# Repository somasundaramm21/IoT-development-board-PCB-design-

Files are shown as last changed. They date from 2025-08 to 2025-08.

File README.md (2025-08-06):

# IoT-development-board-PCB-design-
PCB Design and Kicad files for IoT development board

# 🔧 ESP32-C3 IoT Development Board – Designed with KiCad 8

This repository showcases the complete design journey of a **medium-complexity, four-layer IoT development board**, created using **KiCad 8**. The board features the **ESP32-C3** microcontroller along with built-in **environmental sensors**, **flash memory**, **microSD card support**, and a robust **power management system**—making it a powerful and flexible platform for modern IoT applications.

Unlike previous KiCad projects where I only explored new features, this time I set out to **test KiCad 8 in a real-world design workflow**—from schematic to layout, all the way to manufacturing and hardware validation. The result is this versatile, fully functional development board, designed, tested, and optimized using KiCad 8's latest capabilities.

---

## ✨ Key Features

- ✅ Real-world hardware tested with iterative debugging
- 🛠️ Designed entirely in **KiCad 8**
- ⚡️ Powered by **ESP32-C3** (RISC-V + Wi-Fi + BLE)
- 🔋 Battery and USB-C powered with onboard charging circuit
- 📦 Includes **SPI flash** and **microSD card** for flexible data storage
- 🌡️ Built-in sensors for real-time environmental monitoring
- 🧠 Expandable with AI/LLM capabilities using OpenAI-ESP32

---

## 📐 Tech Specs

### 🧠 Core Components

- **Microcontroller**: ESP32-C3 (RISC-V, Wi-Fi 4, Bluetooth Low Energy)
- **Power Input**: USB-C (for power and data) or LiPo battery (via JST)
- **Power Management**:
  - Dedicated LiPo charging circuit
  - Onboard 3.3V and 5V voltage regulators
- **Storage**:
  - MicroSD card slot for local logging
  - External SPI Flash for config/firmware/data

### 🌡️ Sensors & Inputs

- **BME280**: Temperature, humidity, and pressure
- **Ambient Light Sensor**
- **Microphone with Pre-Amplifier**: Sound monitoring and audio input

### 🔌 Interfaces

- **Protocols**: I2C, SPI
- **USB-to-UART Bridge**: For easy programming and serial debugging
- **GPIO Header**: Expandable for external devices/sensors
- **Test Points**: Available for hardware probing and diagnostics

### 🎛️ User Interaction

- **Buttons**: Boot and Reset
- **Indicators**: Status LEDs for power, charge, and operation
- **Form Factor**:
  - 4-layer PCB (signal, power, and ground planes)
  - Compact and EMI-conscious layout
  - Designed for manufacturability and hand-assembly

---

## 🌍 Applications

This board is a multipurpose platform designed for both prototyping and deployment in:

### 📊 Environmental Monitoring
Use the BME280 and light sensor to build smart weather stations, monitor air quality, or automate greenhouse conditions.

### 🧪 Data Logging
With both SPI flash and SD card, this board is perfect for remote or mobile data logging applications like field research or industrial monitoring.

### 🔋 Battery-Powered IoT Devices
Efficient power management and LiPo support allow you to create portable IoT nodes, wearables, or smart agriculture tools.

### 🔊 Audio-Responsive Systems
Use the microphone + preamp setup for audio monitoring, voice triggers, or sound-based analytics.

---

## 🤖 AI Integration with OpenAI-ESP32

This board is not just for sensors and data—it's also designed for **edge AI experiments**.

With the **OpenAI-ESP32 Arduino library** provided by Espressif, your IoT board can now:

- 🔈 **Understand Voice Commands**  
  Use the onboard microphone to build a smart home assistant that reacts to your natural language.

- 📈 **Analyze Sensor Trends**  
  Combine sensor data with OpenAI’s LLMs to generate meaningful summaries, alerts, or insights.

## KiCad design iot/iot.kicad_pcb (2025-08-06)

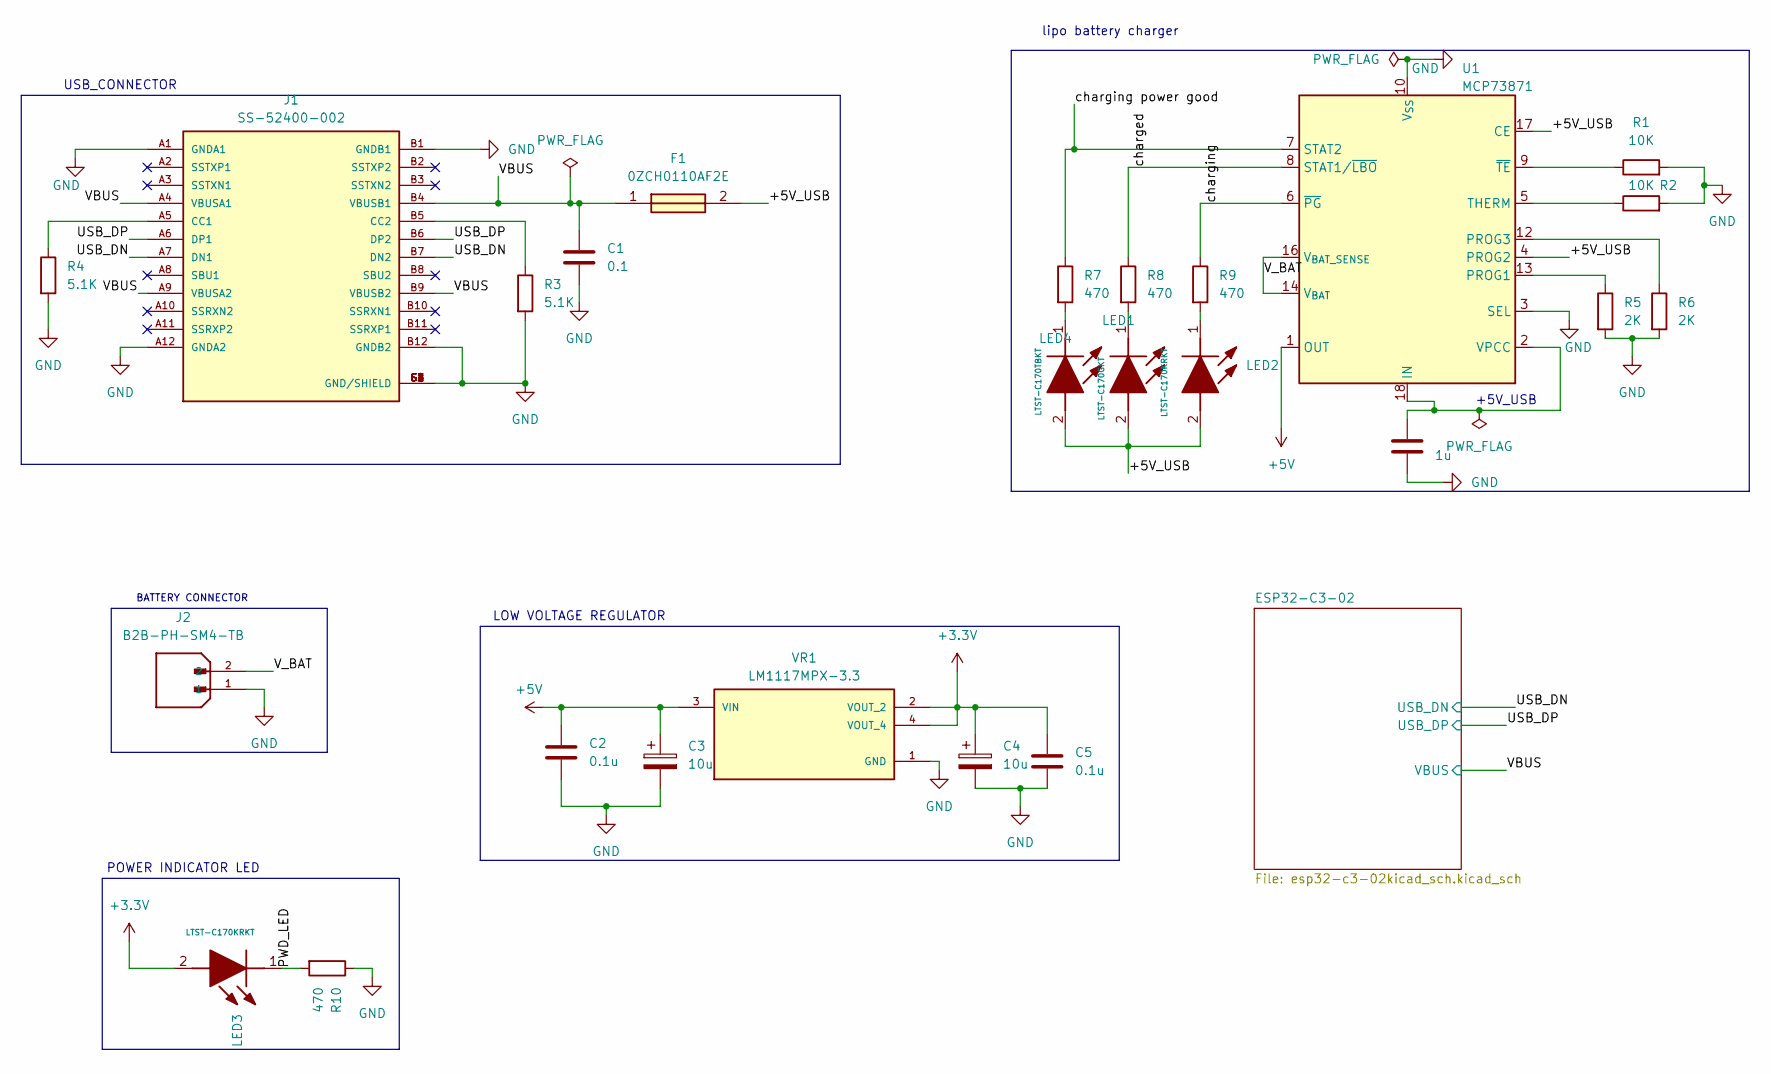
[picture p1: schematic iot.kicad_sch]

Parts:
C1: 0.1; C_0805_2012Metric
C2, C5: 0.1u; C_0805_2012Metric
C3, C4: 10u; RESC3216X125N
C6: 1u; C_0805_2012Metric
F1: 0ZCH0110AF2E; FUSC3226X100N; Manufacturer_Part_Number 0ZCH0110AF2E
J1: SS-52400-002; BELFUSE_SS-52400-002; PARTREV A0
J2: B2B-PH-SM4-TB; JST_B2B-PH-SM4-TB; PARTREV N/A
LED1: LTST-C170GKT; LEDC2012X120N; Manufacturer_Part_Number LTST-C170GKT; Mouser Part Number 859-LTST-C170GKT
LED2, LED3: LTST-C170KRKT; LEDC2012X120N; Manufacturer_Part_Number LTST-C170KRKT; Mouser Part Number 859-LTST-C170KRKT
LED4: LTST-C170TBKT; LEDC2012X120N; Manufacturer_Part_Number LTST-C170TBKT; Mouser Part Number 859-LTST-C170TBKT
R1, R2: 10K; R_0805_2012Metric
R3, R4: 5.1K; R_0805_2012Metric
R5, R6: 2K; R_0805_2012Metric
R7, R8, R9, R10: 470; R_0805_2012Metric
U1: MCP73871; QFN-20-1EP_4x4mm_P0.5mm_EP2.5x2.5mm
VR1: LM1117MPX-3.3; VREG_LM1117MPX-3.3; PARTREV O

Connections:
+3.3V: C4.1, C5.1, LED3.2 (A), VR1.2 (VOUT_2), VR1.4 (VOUT_4); also elsewhere on the board
+5V: C2.1, C3.1, U1.1 (OUT), U1.20 (OUT), VR1.3 (VIN)
/PWD_LED: LED3.1 (K), R10.2
/USB_DN: J1.A7 (DN1), J1.B7 (DN2); also elsewhere on the board
/USB_DP: J1.A6 (DP1), J1.B6 (DP2); also elsewhere on the board
/VBUS: C1.1, F1.1, J1.A4 (VBUSA1), J1.A9 (VBUSA2), J1.B4 (VBUSB1), J1.B9 (VBUSB2); also elsewhere on the board
/V_BAT: J2.2, U1.14 (V_{BAT}), U1.15 (V_{BAT}), U1.16 (V_{BAT_SENSE})
/charged: R8.1, U1.8 (STAT1/~LBO)
/charging: R9.1, U1.6 (~PG)
/charging power good: R7.1, U1.7 (STAT2)
GND: C1.2, C2.2, C3.2, C4.2, C5.2, C6.2, J1.A1 (GNDA1), J1.A12 (GNDA2), J1.B1 (GNDB1), J1.B12 (GNDB2), J1.G1 (GND/SHIELD), J1.G2 (GND/SHIELD), J1.G3 (GND/SHIELD), J1.G4 (GND/SHIELD), J1.S1 (GND/SHIELD), J1.S2 (GND/SHIELD), J1.S3 (GND/SHIELD), J1.S4 (GND/SHIELD), J2.1, R1.2, R2.2, R3.2, R4.2, R5.2, R6.2, R10.1, U1.3 (SEL), U1.10 (V_{SS}), U1.11 (V_{SS}), U1.21 (V_{SS}), VR1.1 (GND); also elsewhere on the board
unnamed: J1.A5 (CC1), R4.1
unnamed: J1.B5 (CC2), R3.1
unnamed: LED1.1 (K), R8.2
unnamed: LED2.1 (K), R9.2
unnamed: LED4.1 (K), R7.2
unnamed: R5.1, U1.13 (PROG1)
unnamed: R6.1, U1.12 (PROG3)
unnamed: R2.1, U1.5 (THERM)
unnamed: R1.1, U1.9 (~TE)

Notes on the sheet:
lipo battery charger
POWER INDICATOR LED
+5V_USB
USB_CONNECTOR
LOW VOLTAGE REGULATOR
BATTERY CONNECTOR

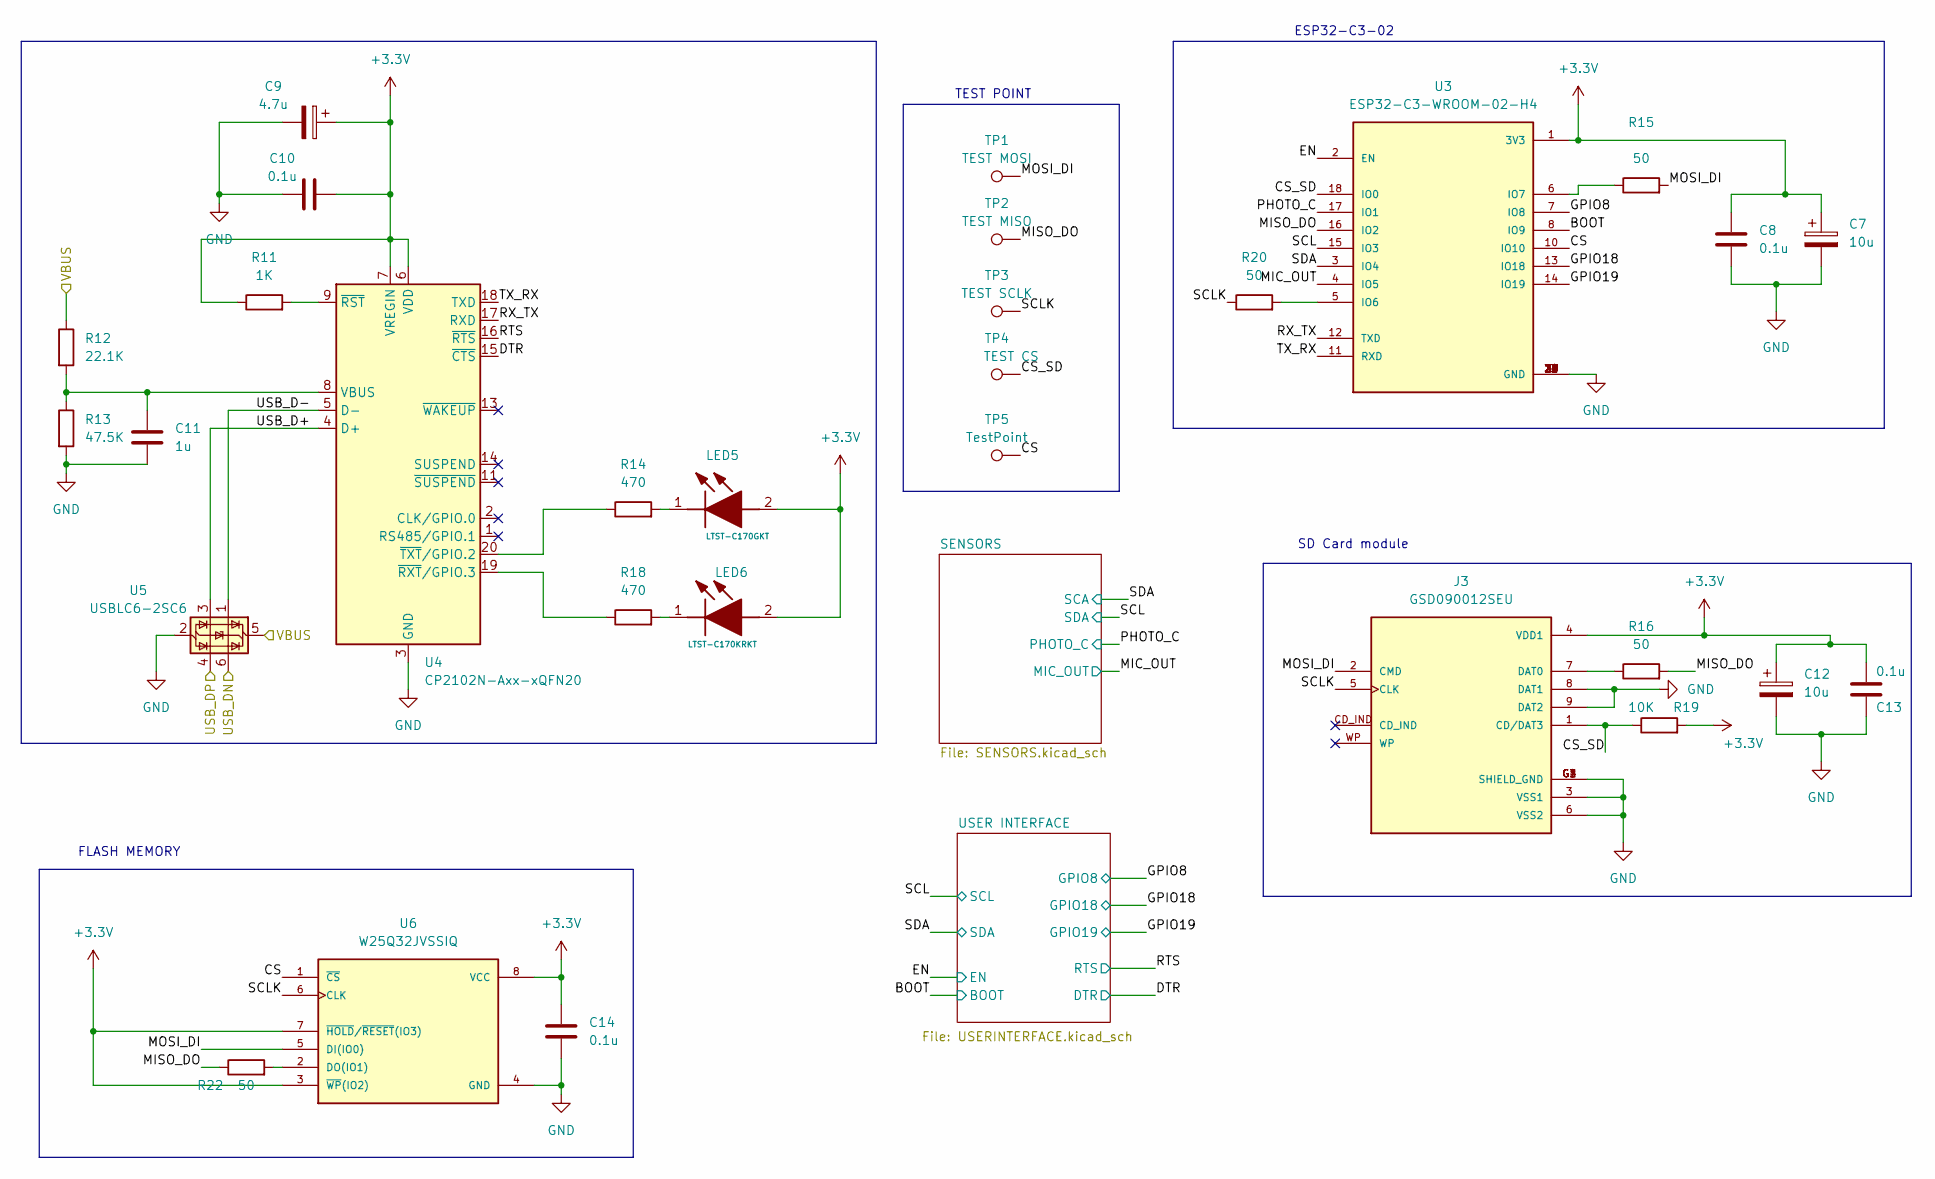
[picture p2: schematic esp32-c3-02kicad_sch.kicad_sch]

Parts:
C7, C12: 10u; RESC3216X125N
C8, C10, C13, C14: 0.1u; C_0805_2012Metric
C9: 4.7u; RESC3216X125N
C11: 1u; C_0805_2012Metric
J3: GSD090012SEU; AMPHENOL_GSD090012SEU; PARTREV E
LED5: LTST-C170GKT; LEDC2012X120N; Manufacturer_Part_Number LTST-C170GKT; Mouser Part Number 859-LTST-C170GKT
LED6: LTST-C170KRKT; LEDC2012X120N; Manufacturer_Part_Number LTST-C170KRKT; Mouser Part Number 859-LTST-C170KRKT
R11: 1K; R_0805_2012Metric
R12: 22.1K; R_0805_2012Metric
R13: 47.5K; R_0805_2012Metric
R14, R18: 470; R_0805_2012Metric
R15, R16, R20, R22: 50; R_0805_2012Metric
R19: 10K; R_0805_2012Metric
TP1: TEST MOSI; TestPoint_Pad_D1.0mm
TP2: TEST MISO; TestPoint_Pad_D1.0mm
TP3: TEST SCLK; TestPoint_Pad_D1.0mm
TP4: TEST CS; TestPoint_Pad_D1.0mm
TP5: TestPoint; TestPoint_Pad_D1.0mm
U3: ESP32-C3-WROOM-02-H4; MODULE_ESP32-C3-WROOM-02-H4; DigiKey_Part_Number 1965-ESP32-C3-WROOM-02-H4CT-ND
U4: CP2102N-Axx-xQFN20; IC_CP2102N-A01-GQFN20
U5: USBLC6-2SC6; SOT-23-6
U6: W25Q32JVSSIQ; SOIC127P790X216-8N; M_PART_NUMBER W25QXX

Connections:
+3.3V: C7.1, C8.1, C9.1, C10.2, C12.1, C13.1, C14.1, J3.4 (VDD1), LED5.2 (A), LED6.2 (A), R11.1, R19.2, U3.1 (3V3), U4.6 (VDD), U4.7 (VREGIN), U6.3 (~WP(IO2)), U6.7 (~HOLD/~RESET(IO3)), U6.8 (VCC); also elsewhere on the board
/ESP32-C3-02/BOOT: U3.8 (IO9); also elsewhere on the board
/ESP32-C3-02/CS: TP5.1, U3.10 (IO10), U6.1 (~CS)
/ESP32-C3-02/CS_SD: J3.1 (CD/DAT3), R19.1, TP4.1, U3.18 (IO0)
/ESP32-C3-02/DTR: U4.15 (~CTS); also elsewhere on the board
/ESP32-C3-02/EN: U3.2 (EN); also elsewhere on the board
/ESP32-C3-02/GPIO8: U3.7 (IO8); also elsewhere on the board
/ESP32-C3-02/GPIO18: U3.13 (IO18); also elsewhere on the board
/ESP32-C3-02/GPIO19: U3.14 (IO19); also elsewhere on the board
/ESP32-C3-02/MIC_OUT: U3.4 (IO5); also elsewhere on the board
/ESP32-C3-02/MISO_DO: R16.2, R22.1, TP2.1, U3.16 (IO2)
/ESP32-C3-02/MOSI_DI: J3.2 (CMD), R15.2, TP1.1, U6.5 (DI(IO0))
/ESP32-C3-02/PHOTO_C: U3.17 (IO1); also elsewhere on the board
/ESP32-C3-02/RTS: U4.16 (~RTS); also elsewhere on the board
/ESP32-C3-02/RX_TX: U3.12 (TXD), U4.17 (RXD)
/ESP32-C3-02/SCL: U3.15 (IO3); also elsewhere on the board
/ESP32-C3-02/SCLK: J3.5 (CLK), R20.1, TP3.1, U6.6 (CLK)
/ESP32-C3-02/SDA: U3.3 (IO4); also elsewhere on the board
/ESP32-C3-02/TX_RX: U3.11 (RXD), U4.18 (TXD)
/ESP32-C3-02/USB_D+: U4.4 (D+), U5.3 (I/O2)
/ESP32-C3-02/USB_D-: U4.5 (D-), U5.1 (I/O1)
/USB_DN: U5.6 (I/O1); also elsewhere on the board
/USB_DP: U5.4 (I/O2); also elsewhere on the board
/VBUS: R12.1, U5.5 (VBUS); also elsewhere on the board
GND: C7.2, C8.2, C9.2, C10.1, C11.2, C12.2, C13.2, C14.2, J3.3 (VSS1), J3.6 (VSS2), J3.8 (DAT1), J3.9 (DAT2), J3.G1 (SHIELD_GND), J3.G2 (SHIELD_GND), J3.G3 (SHIELD_GND), J3.G4 (SHIELD_GND), R13.2, U3.9 (GND), U3.19 (GND), U3.20 (GND), U3.21 (GND), U3.22 (GND), U3.23 (GND), U3.24 (GND), U3.25 (GND), U3.26 (GND), U3.27 (GND), U3.28 (GND), U3.29 (GND), U3.30 (GND), U3.31 (GND), U3.32 (GND), U3.33 (GND), U3.34 (GND), U3.35 (GND), U3.36 (GND), U3.37 (GND), U3.38 (GND), U3.39 (GND), U4.3 (GND), U4.12 (GND), U4.21 (GND), U5.2 (GND), U6.4 (GND); also elsewhere on the board
unnamed: J3.7 (DAT0), R16.1
unnamed: LED5.1 (K), R14.2
unnamed: LED6.1 (K), R18.2
unnamed: R20.2, U3.5 (IO6)
unnamed: R15.1, U3.6 (IO7)
unnamed: C11.1, R12.2, R13.1, U4.8 (VBUS)
unnamed: R11.2, U4.9 (~RST)
unnamed: R18.1, U4.19 (~RXT/GPIO.3)
unnamed: R14.1, U4.20 (~TXT/GPIO.2)
unnamed: R22.2, U6.2 (DO(IO1))

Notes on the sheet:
TEST POINT
ESP32-C3-02
FLASH MEMORY
SD Card module

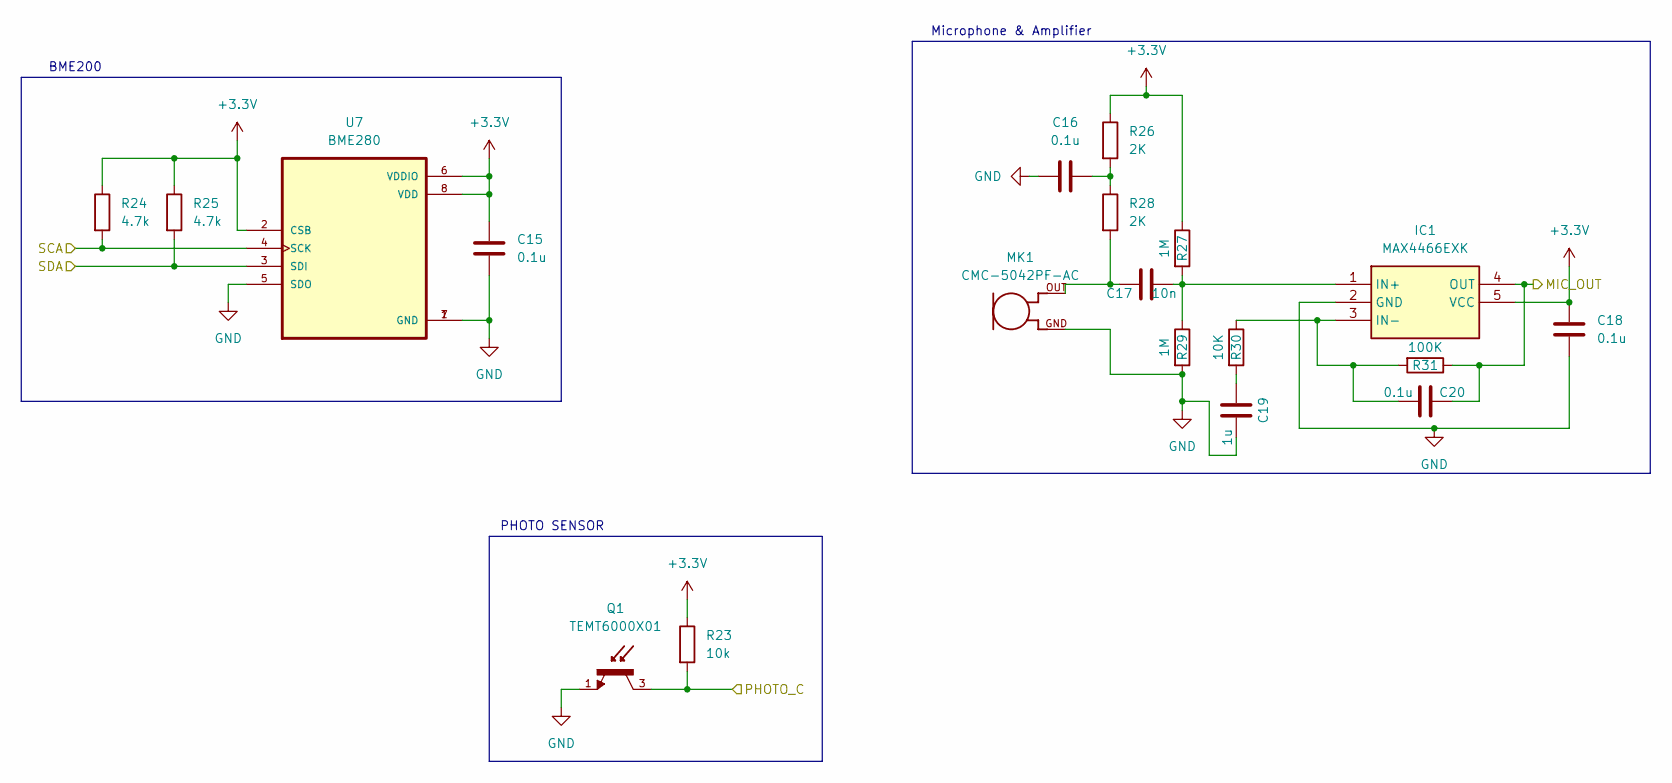
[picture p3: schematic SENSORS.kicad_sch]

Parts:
C15, C16, C18, C20: 0.1u; C_0805_2012Metric
C17: 10n; C_0805_2012Metric
C19: 1u; C_0805_2012Metric
IC1: MAX4466EXK; SOT65P210X110-5N; Manufacturer_Part_Number MAX4466EXK; Mouser Part Number N/A
MK1: CMC-5042PF-AC; CUI_CMC-5042PF-AC
Q1: TEMT6000X01; TRANS_TEMT6000X01; PARTREV 1.9
R23: 10k; R_0805_2012Metric
R24, R25: 4.7k; R_0805_2012Metric
R26, R28: 2K; R_0805_2012Metric
R27, R29: 1M; R_0805_2012Metric
R30: 10K; R_0805_2012Metric
R31: 100K; R_0805_2012Metric
U7: BME280; PSON65P250X250X100-8N

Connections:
+3.3V: C15.1, C18.1, IC1.5 (VCC), R23.1, R24.1, R25.1, R26.1, R27.1, U7.2 (CSB), U7.6 (VDDIO), U7.8 (VDD); also elsewhere on the board
/ESP32-C3-02/MIC_OUT: C20.2, IC1.4 (OUT), R31.1; also elsewhere on the board
/ESP32-C3-02/PHOTO_C: Q1.3, R23.2; also elsewhere on the board
/ESP32-C3-02/SCL: R25.2, U7.3 (SDI); also elsewhere on the board
/ESP32-C3-02/SDA: R24.2, U7.4 (SCK); also elsewhere on the board
GND: C15.2, C16.1, C18.2, C19.1, IC1.2 (GND), MK1.GND, Q1.1, R29.2, U7.1 (GND), U7.5 (SDO), U7.7 (GND); also elsewhere on the board
unnamed: C16.2, R26.2, R28.1
unnamed: C17.2, MK1.OUT, R28.2
unnamed: C19.2, R30.2
unnamed 34: C17.1, IC1.1 (IN+), R27.2, R29.1; also elsewhere on the board
unnamed 35: C20.1, IC1.3 (IN-), R30.1, R31.2; also elsewhere on the board

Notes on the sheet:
PHOTO SENSOR
Microphone & Amplifier
BME200

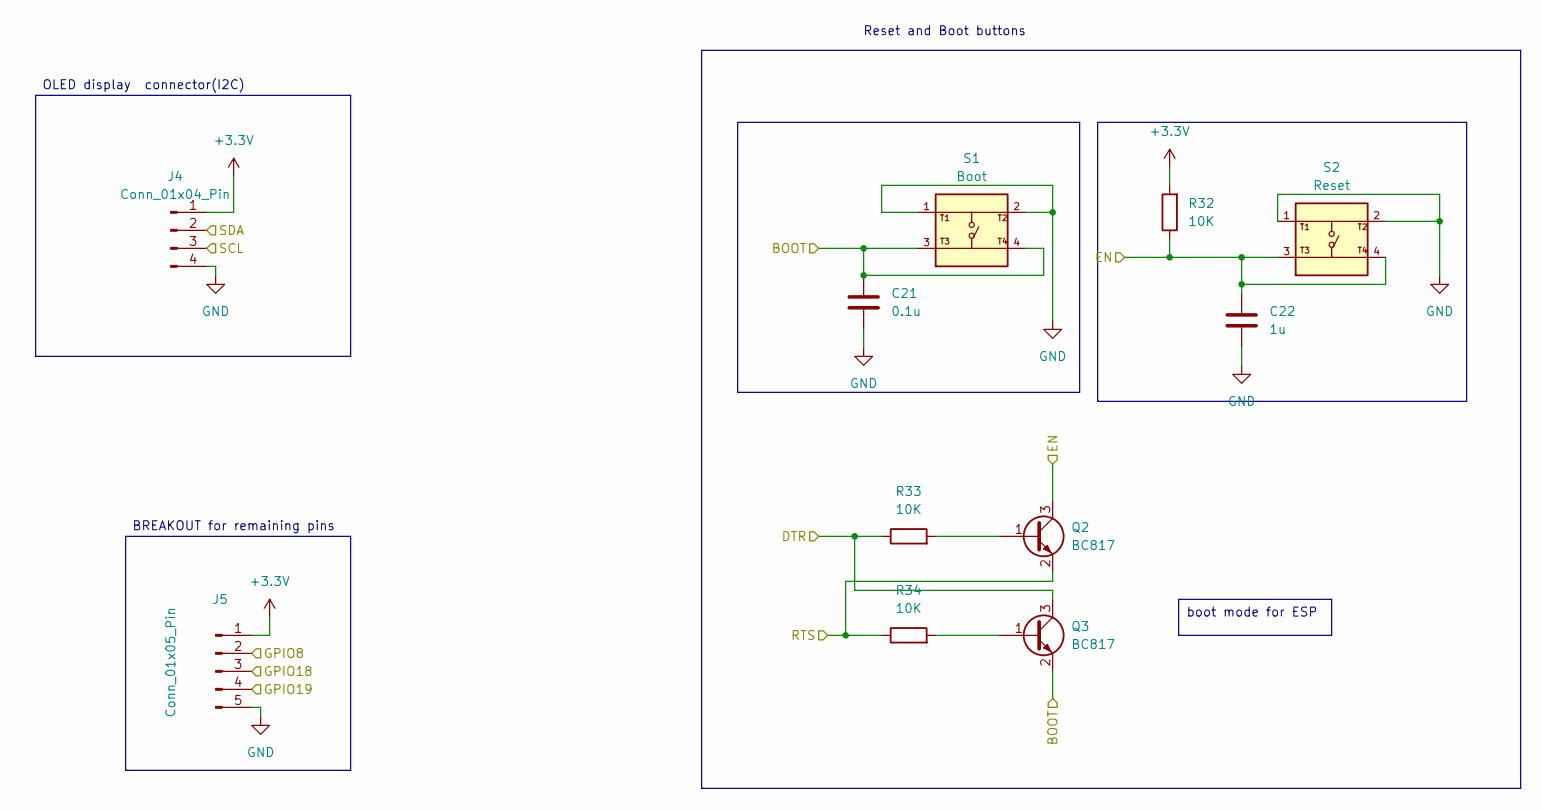
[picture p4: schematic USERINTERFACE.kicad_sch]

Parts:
C21: 0.1u; C_0805_2012Metric
C22: 1u; C_0805_2012Metric
J4: Conn_01x04_Pin; PinHeader_1x04_P2.54mm_Vertical
J5: Conn_01x05_Pin; PinHeader_1x05_P2.54mm_Vertical
Q2, Q3: BC817; SOT-23
R32, R33, R34: 10K; R_0805_2012Metric
S1: Boot; SW_USLPT2819DT2TR; PARTREV P
S2: Reset; SW_USLPT2819DT2TR; PARTREV P

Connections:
+3.3V: J4.1, J5.1, R32.2; also elsewhere on the board
/ESP32-C3-02/BOOT: C21.1, Q3.2 (E), S1.3, S1.4; also elsewhere on the board
/ESP32-C3-02/DTR: Q3.3 (C), R33.1; also elsewhere on the board
/ESP32-C3-02/EN: C22.1, Q2.3 (C), R32.1, S2.3, S2.4; also elsewhere on the board
/ESP32-C3-02/GPIO8: J5.2; also elsewhere on the board
/ESP32-C3-02/GPIO18: J5.3; also elsewhere on the board
/ESP32-C3-02/GPIO19: J5.4; also elsewhere on the board
/ESP32-C3-02/RTS: Q2.2 (E), R34.1; also elsewhere on the board
/ESP32-C3-02/SCL: J4.3; also elsewhere on the board
/ESP32-C3-02/SDA: J4.2; also elsewhere on the board
GND: C21.2, C22.2, J4.4, J5.5, S1.1, S1.2, S2.1, S2.2; also elsewhere on the board
unnamed: Q2.1 (B), R33.2
unnamed: Q3.1 (B), R34.2

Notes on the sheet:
boot mode for ESP
OLED display connector(I2C)
Reset and Boot buttons
BREAKOUT for remaining pins

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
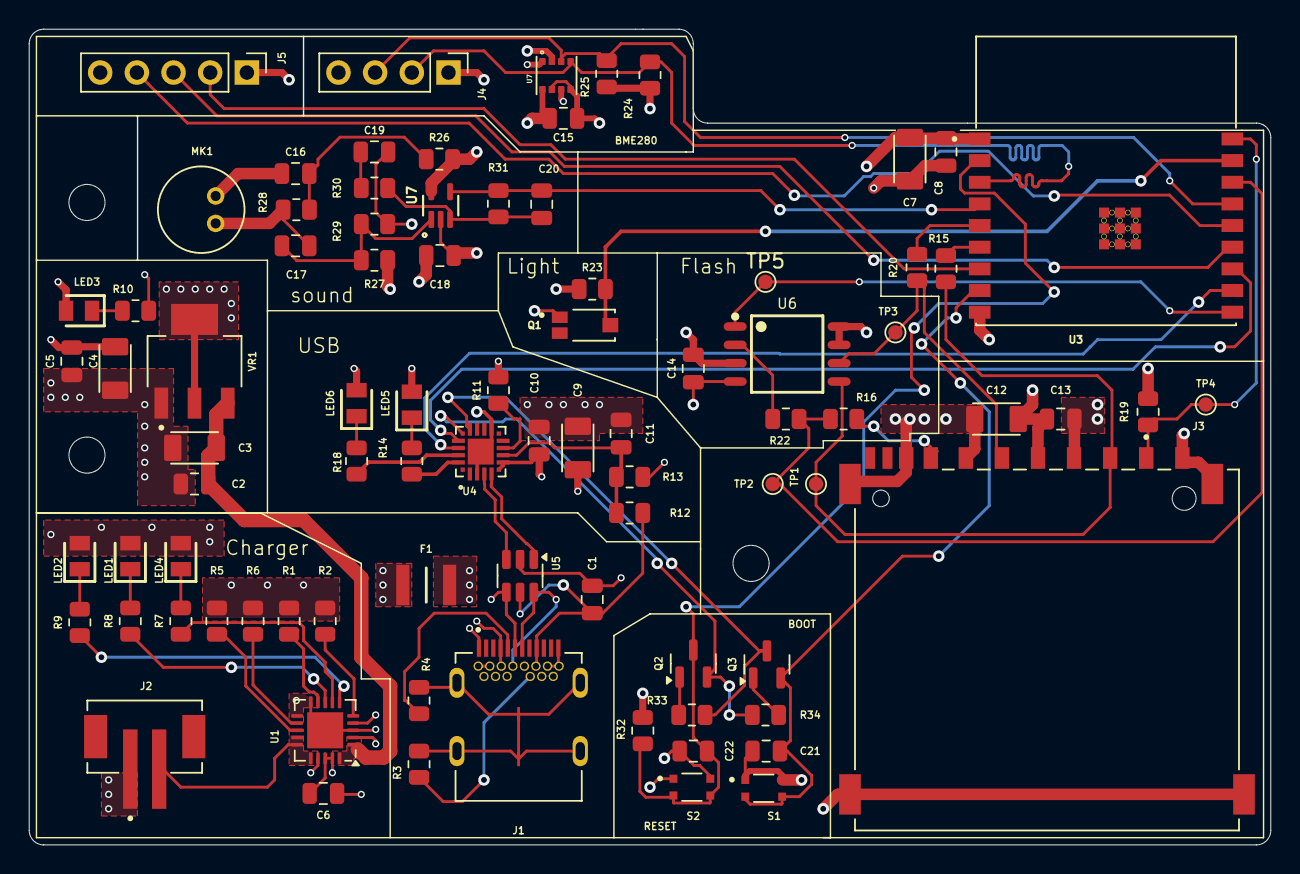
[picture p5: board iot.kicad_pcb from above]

Board: 4 copper layers, 86.0 x 56.5 mm, 85 parts (0 on the bottom side), 58 nets.

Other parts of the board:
U7#2: MAX4466EXK; SOT65P210X110-5N

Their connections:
+3.3V: U7#2.5 (VCC); also elsewhere on the board
/ESP32-C3-02/MIC_OUT: U7#2.4 (OUT); also elsewhere on the board
GND: U7#2.2 (GND); also elsewhere on the board
unnamed 34: U7#2.1 (IN+); also elsewhere on the board
unnamed 35: U7#2.3 (IN-); also elsewhere on the board
